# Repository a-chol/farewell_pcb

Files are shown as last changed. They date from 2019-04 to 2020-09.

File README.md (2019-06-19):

# Farewell

The Farewell is the cheapest 3x3 macropad I could make, with joystick and rotary encoder support.

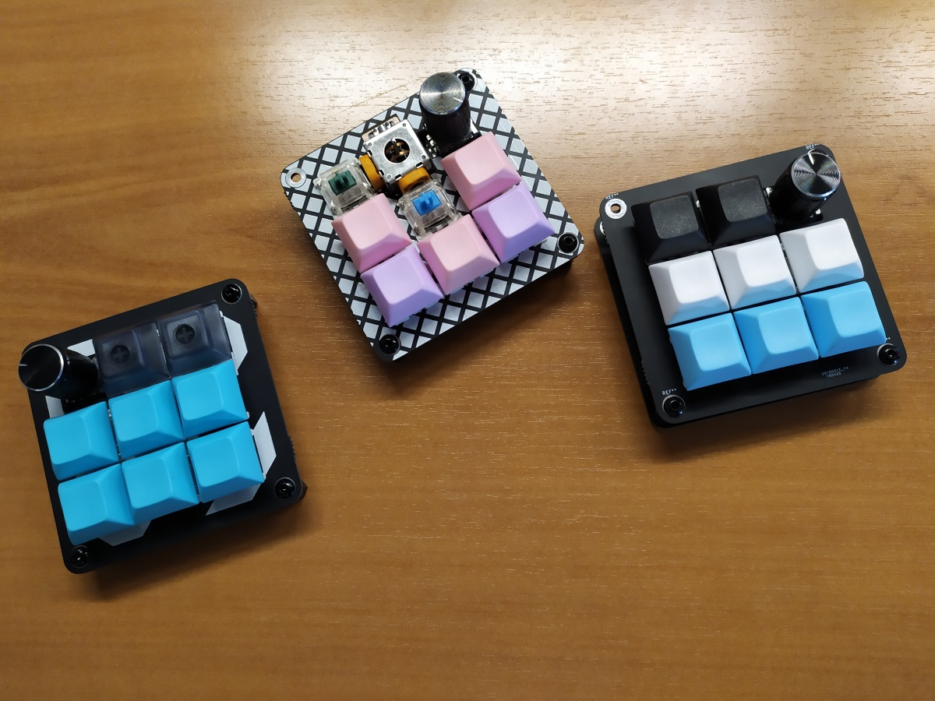
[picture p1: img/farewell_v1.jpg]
farewell_v1


The cost per unit is around $13 with switches, encoders, diodes and keycaps, for 10 units.

Disclaimer : This is not a final design. Problems identified following the first batch are listed in the "To do" section.

# Features
The PCB provides breakout front and back plate.
It supports : 
 * 9 switches (MX or Alps) in a 3x3 matrix
 * up to two rotary encoders at the top corner positions
 * one dual-axis joystick at the top center position
 * pro-micro footprint for the controller
 * choice of black or printed front and backplate
 * specific frontplate for joystick use

# To do
Here are the problems to be fixed for the second iteration : 
 * Make more space between switch footprints to allow joystick to tilt and keycaps to be mounted (implies non-standard switch spacing)
 * cut PCB corners to make space for standoffs
 * invert pro-micro footprint to have the usb port higher, preventing backplate from blocking cable
 * clean off silk printing from useless markings
 * print the FW on the front-plate in a more visible way (maybe)
 * enlarge a little bit the frontplate joystick cutout
 * move SDA pinhole to prevent confusion in rotary encoder positioning
 * mark back and front of the PCB
 
[Build instructions are available here](BuildInstructions_v1.md)

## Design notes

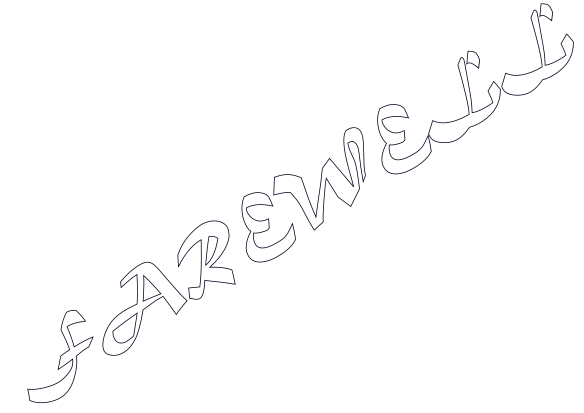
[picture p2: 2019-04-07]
farewell.png

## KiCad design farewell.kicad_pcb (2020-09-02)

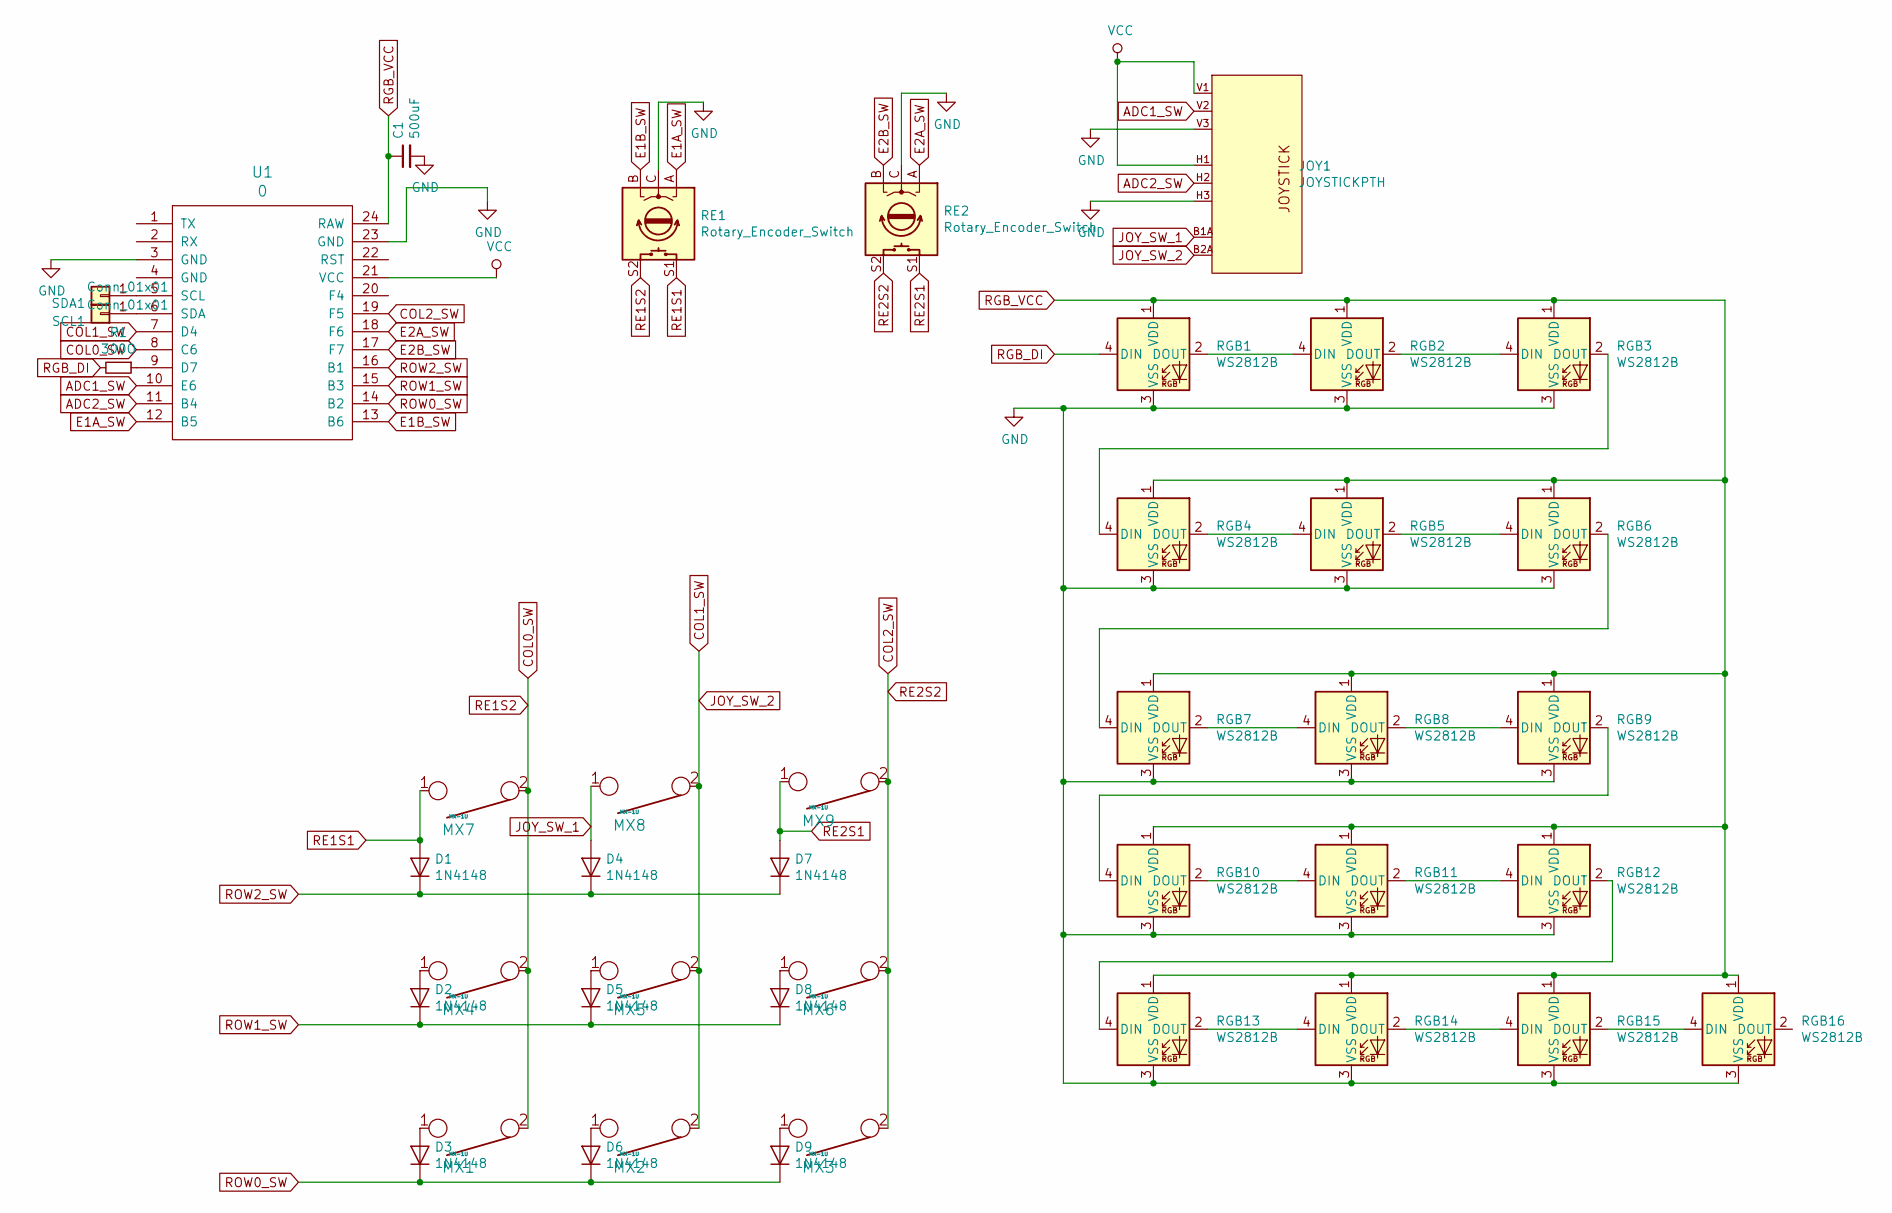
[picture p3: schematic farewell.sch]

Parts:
C1: 500uF; CP_Radial_D8.0mm_P3.50mm
D1, D2, D3, D4, D5, D6, D7, D8, D9: 1N4148; D_SOD123_axial
JOY1: JOYSTICKPTH; JOYSTICK
MX1, MX2, MX3, MX4, MX5, MX6, MX7, MX8, MX9: MX-1U; MX-Alps-Choc-1U-NoLED-noprongs
R1: 300O; R_Axial_DIN0207_L6.3mm_D2.5mm_P7.62mm_Horizontal
RE1, RE2: Rotary_Encoder_Switch; RotaryEncoder_Alps_EC11E-Switch_Vertical_H20mm
RGB1, RGB2, RGB3, RGB4, RGB5, RGB6, RGB7, RGB8, RGB9, RGB10, RGB11, RGB12, RGB13, RGB14, RGB15, RGB16: WS2812B; LED_WS2812B_SK6812_MINI-E_HYBRID
SCL1: Conn_01x01; PIN_1
SDA1: Conn_01x01; PIN_1
U1: 0; keebio_ArduinoProMicro-ZigZag

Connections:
ADC1_SW: JOY1.V2 (V), U1.10 (E6)
ADC2_SW: JOY1.H2 (H), U1.11 (B4)
COL0_SW: MX1.2, MX4.2, MX7.2, RE1.S2, U1.8 (C6)
COL1_SW: JOY1.B2A (SEL-), MX2.2, MX5.2, MX8.2, U1.7 (D4)
COL2_SW: MX3.2, MX6.2, MX9.2, RE2.S2, U1.19 (F5)
E1A_SW: RE1.A, U1.12 (B5)
E1B_SW: RE1.B, U1.13 (B6)
E2A_SW: RE2.A, U1.18 (F6)
E2B_SW: RE2.B, U1.17 (F7)
GND: C1.2, JOY1.H3 (H-), JOY1.V3 (V-), RE1.C, RE2.C, RGB1.3 (VSS), RGB2.3 (VSS), RGB3.3 (VSS), RGB4.3 (VSS), RGB5.3 (VSS), RGB6.3 (VSS), RGB7.3 (VSS), RGB8.3 (VSS), RGB9.3 (VSS), RGB10.3 (VSS), RGB11.3 (VSS), RGB12.3 (VSS), RGB13.3 (VSS), RGB14.3 (VSS), RGB15.3 (VSS), RGB16.3 (VSS), U1.3 (GND), U1.23 (GND)
JOY_SW_1: D4.2 (A), JOY1.B1A (SEL+), MX8.1
unnamed: D2.2 (A), MX4.1
unnamed: D3.2 (A), MX1.1
unnamed: D5.2 (A), MX5.1
unnamed: D6.2 (A), MX2.1
unnamed: D8.2 (A), MX6.1
unnamed: D9.2 (A), MX3.1
unnamed: R1.1, U1.9 (D7)
unnamed: RGB1.2 (DOUT), RGB2.4 (DIN)
unnamed: RGB2.2 (DOUT), RGB3.4 (DIN)
unnamed: RGB3.2 (DOUT), RGB4.4 (DIN)
unnamed: RGB4.2 (DOUT), RGB5.4 (DIN)
unnamed: RGB5.2 (DOUT), RGB6.4 (DIN)
unnamed: RGB6.2 (DOUT), RGB7.4 (DIN)
unnamed: RGB7.2 (DOUT), RGB8.4 (DIN)
unnamed: RGB8.2 (DOUT), RGB9.4 (DIN)
unnamed: RGB10.2 (DOUT), RGB11.4 (DIN)
unnamed: RGB9.2 (DOUT), RGB10.4 (DIN)
unnamed: RGB11.2 (DOUT), RGB12.4 (DIN)
unnamed: RGB12.2 (DOUT), RGB13.4 (DIN)
unnamed: RGB13.2 (DOUT), RGB14.4 (DIN)
unnamed: RGB14.2 (DOUT), RGB15.4 (DIN)
unnamed: RGB15.2 (DOUT), RGB16.4 (DIN)
unnamed: SCL1.1, U1.6 (SDA)
unnamed: SDA1.1, U1.5 (SCL)
RE1S1: D1.2 (A), MX7.1, RE1.S1
RE2S1: D7.2 (A), MX9.1, RE2.S1
RGB_DI: R1.2, RGB1.4 (DIN)
RGB_VCC: C1.1, RGB1.1 (VDD), RGB2.1 (VDD), RGB3.1 (VDD), RGB4.1 (VDD), RGB5.1 (VDD), RGB6.1 (VDD), RGB7.1 (VDD), RGB8.1 (VDD), RGB9.1 (VDD), RGB10.1 (VDD), RGB11.1 (VDD), RGB12.1 (VDD), RGB13.1 (VDD), RGB14.1 (VDD), RGB15.1 (VDD), RGB16.1 (VDD), U1.24 (RAW)
ROW0_SW: D3.1 (K), D6.1 (K), D9.1 (K), U1.14 (B2)
ROW1_SW: D2.1 (K), D5.1 (K), D8.1 (K), U1.15 (B3)
ROW2_SW: D1.1 (K), D4.1 (K), D7.1 (K), U1.16 (B1)
VCC: JOY1.H1 (H+), JOY1.V1 (V+), U1.21 (VCC)

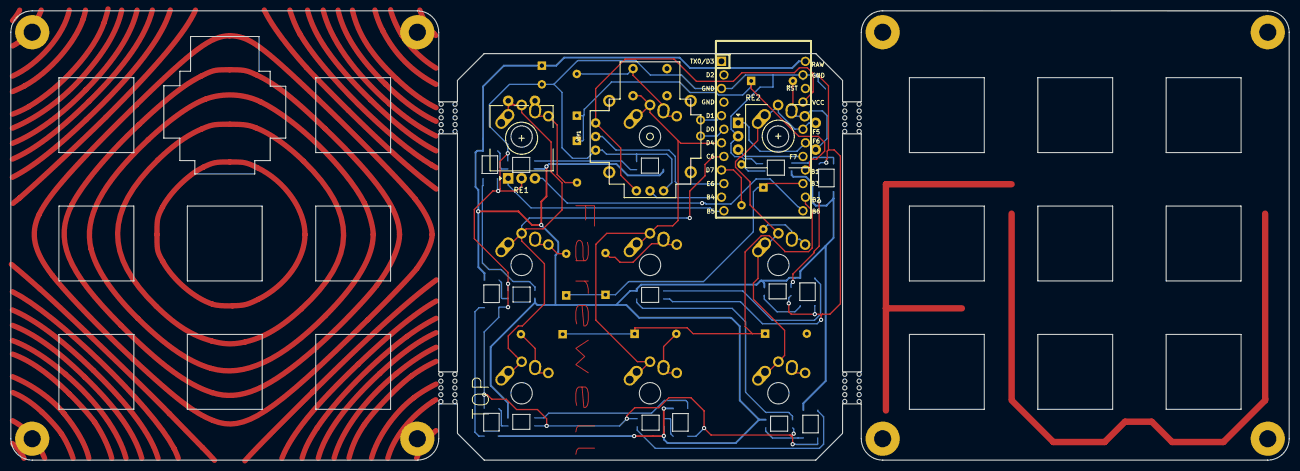
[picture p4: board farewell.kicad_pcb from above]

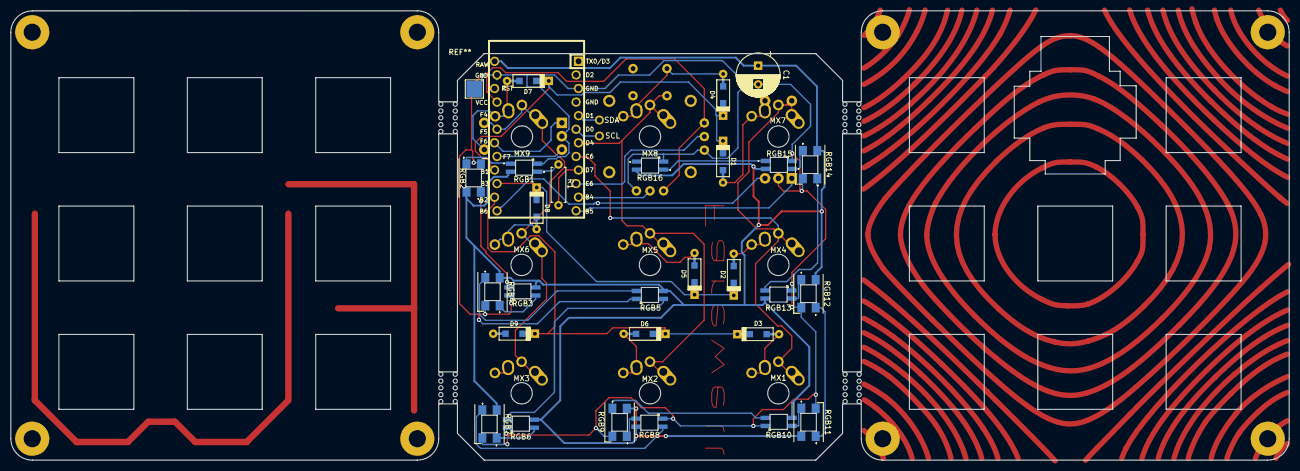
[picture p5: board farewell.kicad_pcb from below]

Board: 2 copper layers, 239.0 x 84.0 mm, 42 parts (27 on the bottom side), 43 nets.

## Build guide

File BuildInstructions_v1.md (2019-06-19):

# Build Instructions for the v1 PCB

 1. Break out the PCB into the main PCB and the two back/front plate
 2. Cut out 3 mm of the 3 corners of the PCB to make room for the standoff (except the corner where the controller will be soldered)
 3. Put the diodes in each position (even at encoders and joystick location) and solder them. Be careful to put the diode in the correct direction.
 4. lower the plastic piece of both controler headers so that the pins are flush through the PCB
 5. Solder the controler headers from the top of the PCB (switch-side)
 6. Cut the headers'pins at 2 mm above the plastic spacers (diodes side)
 7. solder joystick and rotary encoders
 8. put the switches on your selected front plate and insert them on the PCB
 9. solder the switches
 10. position and solder the controler, components facing outwards
 11. mount the front plate to the back plate using the screws and standoffs on the 3 working corners.

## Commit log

2019-04-07 farewell with two encoders and middle pro micro
    [farewell.kicad_pcb, farewell.sch]
2019-06-13 farewell v1 pcb
    [farewell.kicad_pcb, farewell.sch]
2019-06-14 Fixup project path references and add submodules for required libraries
    [farewell.kicad_pcb, farewell.sch]
2020-02-05 [WIP] Added RGB plate
    [farewell.kicad_pcb, farewell.sch]
2020-02-26 rgb support with castellated connection
    [farewell.kicad_pcb, farewell.sch]
2020-02-27 use female header pins for connecting switch pcb to mcu pcb
    [farewell.kicad_pcb, farewell.sch]
2020-05-21 pcb with hybrid sk6812 mini-e/ws2812B footprint and mx/choc compatible switch footprint
    [farewell.kicad_pcb, farewell.sch]
2020-09-02 Complete pcb
    [farewell.kicad_pcb, farewell.sch]
2020-09-02 rotary encoder space in plates reset to standard size
    [farewell.kicad_pcb]
